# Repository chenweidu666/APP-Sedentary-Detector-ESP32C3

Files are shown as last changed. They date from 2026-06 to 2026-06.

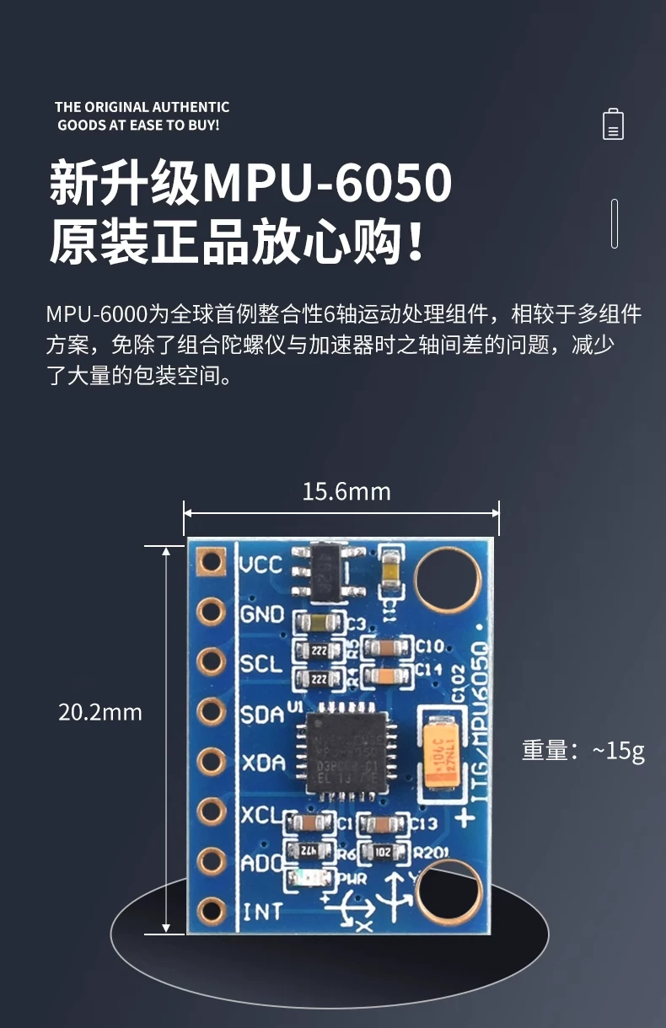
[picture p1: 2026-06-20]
hardware/images/6050.png

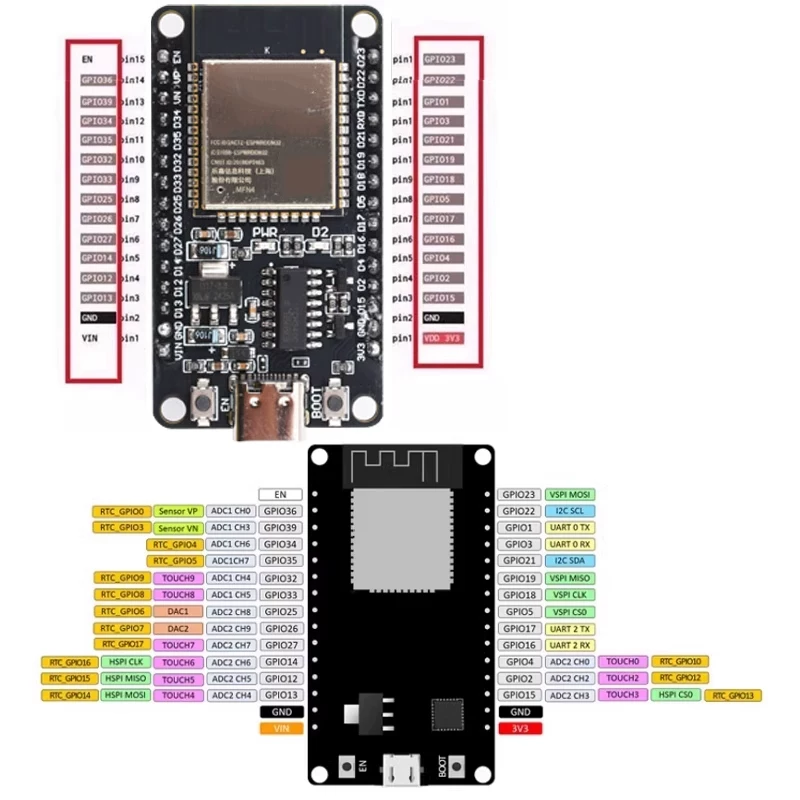
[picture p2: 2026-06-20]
hardware/images/esp32-wroom-32-pinout.jpg

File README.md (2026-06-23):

# Sedentary Detector ESP32 - 久坐检测器

<p align="center">
  
  
  
  
  
</p>

基于 **ESP32-WROOM-32** + **GY-87**（MPU6050）+ **OLED** 的椅子久坐检测器载板方案。本仓库**仅保留硬件**（BOM、接线、KiCad）；固件与联调在独立项目中完成。

**策略**：现成模块 + 定制载板 PCB 插接互连；PM11 锂电包供电（USB 充电，模块自带开关）。

**载板布线节奏**：KiCad 已完成原理图、布局与网络分配；**PCB 尚未布线**。固件与算法仍在 [03](../../03-ESP32-OLED-Button-Demo) / [04](../../04-MCU-GY87-Debug) 中联调，接口与引脚稳定后再走线、DRC、打样，避免返工。

## 当前进度

| 模块 | 状态 |
|---|---|
| 硬件方案 | ✅ MCU + GY-87 + OLED + PM11（无载板按键/开关） |
| 原理图 | ✅ v0.6（J1–J4 网络） |
| 载板 PCB | 🔧 v0.4 已布局 + 网络分配 + J2 对齐；**未布线**（等软件联调稳定后走线打样） |
| GY-87 / IMU 联调 | 🔧 [04-MCU-GY87-Debug](../../04-MCU-GY87-Debug) 调试中 |
| OLED 联调 | 🔧 [03-ESP32-OLED-Button-Demo](../../03-ESP32-OLED-Button-Demo) 调试中 |
| 3D 底座 | ⏳ 待设计 |

## 系统架构

```
         USB 充电
            │
    ┌───────┴────────────────────────────┐
    │  PM11 电源 (自带 ON/OFF)              │
    │       5V / GND                       │
    └───────┬────────────────────────────┘
            │ J3
    ┌───────┴────────────────────────────┐
    │  载板 PCB (100×80)                  │
    │  ┌─────────┐  I2C   ┌──────────┐   │
    │  │ GY-87   │═══════│ ESP32    │   │
    │  │ J2      │       │ DevKitC  │   │
    │  └─────────┘       │ J1       │   │
    │  ┌─────────┐       └──────────┘   │
    │  │ OLED    │═══════ (共享 I2C)     │
    │  │ J4      │                       │
    │  └─────────┘                       │
    └────────────────────────────────────┘
```

检测算法与固件开发见下方**关联软件项目**。

## 文档

| 文档 | 内容 |
|---|---|
| [hardware/HARDWARE.md](hardware/HARDWARE.md) | **硬件权威**：BOM、网络表、模块引脚、电源、PCB 版本 |
| [AGENTS.md](AGENTS.md) | AI / KiCad 自动化工作流 |

### KiCad 载板工程

```bash
kicad hardware/kicad/SedentaryDetector.kicad_pro
```

打样前核对 [hardware/HARDWARE.md §PCB 版本记录](hardware/HARDWARE.md#pcb-版本记录)。

### 关联软件项目（本仓库不含固件源码）

| 项目 | 内容 |
|---|---|
| [03-ESP32-OLED-Button-Demo](../../03-ESP32-OLED-Button-Demo) | SSD1306 OLED + I2C |
| [04-MCU-GY87-Debug](../../04-MCU-GY87-Debug) | GY-87 / MPU6050、久坐检测、BLE |

## 项目结构

```
02-APP-Sedentary-Detector-ESP32/
├── README.md          # 本文件（仓库唯一 README）
├── AGENTS.md
└── hardware/
    ├── HARDWARE.md
    ├── images/
    ├── kicad/
    └── scripts/
```

## 里程碑

| 阶段 | 目标 | 状态 |
|---|---|---|
| M1 模块联调 | 杜邦线验证 GY-87 + OLED（03/04） | 🔧 |
| M2 载板 | 软件稳定后 PCB 布线 → DRC → 打样焊接 | ⏳ |
| M3 整合 | 载板 + 03/04 固件合并产品化 | ⏳ |

## License

MIT

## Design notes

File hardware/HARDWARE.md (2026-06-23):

# 硬件设计文档

> **主控**：ESP32-WROOM-32 开发板（ESP32-DevKitC 风格，2×15 排针载板）。非 ESP32-C3。

## 采购链接

| 模块 | 链接 |
| --- | --- |
| ESP32-WROOM-32 开发板 | https://detail.tmall.com/item.htm?id=805161973303&skuId=5879086331469 |
| 陀螺仪模块 | **GY-87**（10DOF，固件用 MPU6050） | 淘宝/立创搜 GY-87 |
| PM11锂电池包 (3.7V+充电+升压5V/2.4A) | https://item.taobao.com/item.htm?id=1007451636387&skuId=6002389453662 |
| 0.96寸 OLED (I2C) | 128×64 SSD1306, 4Pin (VCC/GND/SCL/SDA) | 淘宝搜 0.96 OLED I2C |

---

## 模块引脚

### ESP32-WROOM-32 开发板 (ESP32-DevKitC 风格)

ESP32-WROOM-32 引脚图

```
尺寸: 51.85 × 23.5 mm
引脚: 左列 15pin + 右列 14pin, 2.54mm 间距, 排针间距 23.5mm
安装孔: 4× φ3mm, 距边 3mm
```

#### 左侧引脚 (从上到下, 15 pin)

| Pin | 丝印 | 功能说明 |
| --- | --- | --- |
| 1 | EN | 使能/复位引脚 (高电平有效) |
| 2 | UP (VP) | GPIO36, ADC1_CH0, 仅输入 |
| 3 | UN (VN) | GPIO39, ADC1_CH3, 仅输入 |
| 4 | D34 | GPIO34, ADC1_CH6, 仅输入 |
| 5 | D35 | GPIO35, ADC1_CH7, 仅输入 |
| 6 | D32 | GPIO32, ADC1_CH4 / TOUCH9  |
| 7 | D33 | GPIO33, ADC1_CH5 / TOUCH8  |
| 8 | D25 | GPIO25, ADC2_CH8 / DAC_1 |
| 9 | D26 | GPIO26, ADC2_CH9 / DAC_2 |
| 10  | D27 | GPIO27, ADC2_CH7 / TOUCH7  |
| 11  | D14 | GPIO14, ADC2_CH6 / TOUCH6  |
| 12  | D12 | GPIO12, ADC2_CH5 / TOUCH5  |
| 13  | D13 | GPIO13, ADC2_CH4 / TOUCH4  |
| 14  | GND | 接地 |
| 15  | VIN | 外部电源输入 (5V) |

#### 右侧引脚 (从上到下, 15 pin)

| Pin | 丝印 | 功能说明 |
| --- | ---- | --- |
| 16  | D23  | GPIO23, VSPI MOSI |
| 17  | D22  | GPIO22, I2C SCL (备用) |
| 18  | TXD  | GPIO1, UART0 TXD |
| 19  | RXD  | GPIO3, UART0 RXD |
| 20  | D21  | GPIO21, I2C SDA (备用) |
| 21  | D19  | GPIO19, VSPI MISO |
| 22  | D18  | GPIO18, VSPI SCK |
| 23  | D5 | GPIO5, VSPI SS / I2C SCL |
| 24  | D17  | GPIO17, UART2 TXD |
| 25  | D16  | GPIO16, UART2 RXD |
| 26  | D4 | GPIO4, I2C SDA |
| 27  | D2 | GPIO2, 板载 LED / MPU INT |
| 28  | D15  | GPIO15, U0 RTS |
| 29  | GND  | 接地 |
| 30  | 3V3  | 3.3V 电源输出 |

> ⚠️ 注意事项:
>
> - GPIO34~39 仅输入，无输出、无内上下拉
> - GPIO6~11 被 SPI Flash 占用，不建议使用
> - GPIO12 (D12) 上电影响 Flash 电压 (MTDI)，上电时保持低
> - GPIO0 下载模式 (板子底部 BOOT 按钮)
> - 板载 LED 在 D2 (GPIO2)

### GY-87 模块（正式选型）

GY-87 10DOF 模块实物（联调）

10DOF 蓝板，丝印 **GY-87**（MPU6050 + HMC5883L + BMP180）。久坐检测**仅使用 MPU6050 加速度计**，磁力计/气压计与固件无关。

```
引脚: 1 × 8pin 单排, 2.54mm
模块**背面**丝印（如上图，从左至右）: VCC_IN · 3.3V · GND · SCL · SDA · FSYNC · INTA · DRDY
载板 J2 排母（J2 Pin1 = VCC_IN, Pin8 = DRDY），与模块背照丝印顺序一致
```

#### J2 排母引脚映射（载板 / 直插）

| J2 Pin | GY-87 丝印 | 网络 | 连接 |
| --- | --- | ---- | ---- |
| 1 | **VCC_IN** | 3V3 | ESP32 Pin30 (3V3) |
| 2 | **3.3V** | — | **不接**（NC） |
| 3 | **GND** | GND | ESP32 GND |
| 4 | **SCL** | I2C_SCL | ESP32 Pin23 (D5) |
| 5 | **SDA** | I2C_SDA | ESP32 Pin26 (D4) |
| 6 | **FSYNC** | — | NC |
| 7 | **INTA** | MPU_INT | ESP32 Pin27 (D2) |
| 8 | **DRDY** | — | NC |

I2C 扫描：

```
0x68  MPU6050（固件使用）
0x77  BMP180（GY-87 自带，忽略）
0x1E  HMC5883L（可选，固件未用）
```

> **PCB 版本**：见文末 [PCB 版本记录](#pcb-版本记录)。

#### 杜邦线联调（ESP32 扩展板）

| GY-87 丝印 | 扩展板 | 线色（参考） |
| --- | --- | --- |
| VCC_IN | **3V3** | 红 |
| GND | **GND** | 橙 |
| SCL | **D5** | 黄 |
| SDA | **D4** | 绿 |
| INTA | **D2** | 蓝（可选） |
| 3.3V / FSYNC / DRDY | 不接 | — |

联调已验证（2026-06-22）：`0x68` + `0x77`，竖放基准角约 97°，`mock=0` 正常。

---

### 传感器安装姿态

**当前台架**：GY-87 **竖直立放**（芯片面垂直于桌面），非最终椅子安装姿态。

| 姿态 | 典型读数 | 说明 |
| ---- | --- | ---- |
| 水平放置（Z 轴朝上） | 基准角 ≈ **0°** | 最终坐垫下安装目标姿态 |
| **竖直立放（当前）** | 基准角 ≈ **±90°**（实测约 **97°**） | 正常；算法看 **delta**，不是绝对角 |

竖放时上电校准后 `baseline` 约在 **90° 附近**，静止时 `delta` 应 **< 0.5°**、`state=VAC`。  
有人/受压时 **倾斜 1° 以上**（`delta > 1.0°`）才判为 `OCCUPIED`。

**最终产品**：模块应 **水平** 固定在坐垫下方，装好后串口发 `c` 重校准（基准角约 0°）。

### OLED 显示屏

1.54 寸 OLED（SSD1306, 128×64），I2C 接口，与 GY-87 共享 I2C 总线。

| OLED Pin | 网络 | 接 ESP32 |
|---|---|---|
| VCC | 3V3 | Pin30 (3V3) |
| GND | GND | Pin14/29 (GND) |
| SCL | I2C_SCL | Pin23 (D5) |
| SDA | I2C_SDA | Pin26 (D4) |

I2C 地址：**0x3C**（与 GY-87 的 0x68 不冲突）。

### 供电模块 (PM11 电源板)

供电模块 PCB 布局

集成 **USB 充电 + 锂电管理 + 多路电源输出** 的独立电源板，通过排针向 ESP32 载板供电。

#### 外形尺寸

| 参数 | 值 |
|---|-----|
| PCB 尺寸 | **56.0 × 40.0 mm** |
| 安装孔间距 | 水平 **48.0 mm** × 垂直 **32.0 mm** |
| 安装孔 | 四角 M3（图中标注孔径约 φ4.7 mm，以实物为准） |
| 板厚 | 1.6 mm（常规） |

#### 板载功能

| 功能 | 说明 |
|---|---|
| USB 输入 | 左侧 USB 口，用于充电与外部供电 |
| ON/OFF 开关 | 左侧滑动开关，物理通断输出 |
| 电量指示 | 左侧四档 LED：**100% / 75% / 50% / 25%** |
| 充电管理 | TP4056 类充电 IC + 外围 RC |
| 电池接口 | 顶部 **4Pin** 电池座，丝印 **+ / −** 极性 |
| 电源输出 | 顶部 **2×6** 排针（2.54 mm） |

#### 2×6 排针（本设计关注）

排针位于板子顶部左侧区域；**底排**为常用电源轨（丝印可见）：

| 排针信号 | 说明 | 载板连接 |
|---|---|---|
| **VBAT** | 电池电压（未稳压） | 一般不接 ESP32 |
| **5V** | 升压/稳压 5V 输出 | → ESP32 **Pin15 (VIN)** |
| **3V3** | 3.3V 输出 | 备用；GY-87 从 ESP32 Pin30 取 3V3 |
| GND | 共地 | → ESP32 **Pin14/29** + 载板 GND 铺铜 |

> 上排 6Pin 功能以实物丝印为准；收到模块后**用万用表核对**再焊线。

#### 本设计电源路径

```
USB ──→ [供电模块] ── ON/OFF ──→ 5V 排针 ──→ 载板 ──→ ESP32 Pin15 (VIN)
              │                              │
              └── 电池 (4Pin +/-)             └── GND ──→ ESP32 GND
              └── 电量 LED (100/75/50/25%)

ESP32 板载 LDO: VIN(5V) → 3V3 Pin30 → GY-87 VCC_IN
```

#### 注意事项

1. 电池 **+/−** 切勿接反
2. 开关 OFF 时 ESP32 完全断电；ON 后 5V 才输出到排针
3. 充电时 USB 插入即可，与 ESP32 是否上电无关
4. D2 (GPIO2) 接 GY-87 **INTA**，与 ESP32 板载 LED 共用

---

## 载板全网络表

| 网络 | J1 (ESP32) | J2 (GY-87) | J3 (电源) | J4 (OLED) |
|---|---|---|---|---|
| 3V3 | Pin30 | Pin1(VCC_IN) | — | Pin1(VCC) |
| 5V | Pin15(VIN) | — | Pin2 | — |
| GND | Pin14,29 | Pin3 | Pin1 | Pin2 |
| I2C_SCL | Pin23(D5) | Pin4(SCL) | — | Pin3 |
| I2C_SDA | Pin26(D4) | Pin5(SDA) | — | Pin4 |
| MPU_INT | Pin27(D2) | Pin7(INTA) | — | — |

载板**无**载板级滑动开关与按键；电源通断由 **PM11 自带 ON/OFF** 控制。

---

## 电源路径

```
供电模块 5V 排针 → 载板走线 → ESP32 Pin15 (VIN)
供电模块 GND     → 载板 GND  → ESP32 Pin14/29
```

## 载板 BOM

| # | 元件 | 规格 | 封装 | 数量 |
| - | ---- | ---- | ---- | :--: |
| 1 | ESP32 排母 (左) | 1×15P 2.54mm | 直插 | 1 |
| 2 | ESP32 排母 (右) | 1×15P 2.54mm | 直插 | 1 |
| 3 | GY-87 排母 J2 | 1×8P 2.54mm | 直插 | 1 |
| 4 | OLED 排母 J4 | 1×4P 2.54mm | 直插 | 1 |
| 5 | JST 电源座 J3 | JST-PH 2.0mm 2P | 直插 | 1 |
| 6 | PCB | 100×80mm 2层 1.6mm | - | 5 |

## 固件与交互

本仓库**不包含固件源码**。联调与算法在 sibling 项目中维护：

| 能力 | 项目 |
|---|---|
| GY-87 / MPU6050、久坐检测、BLE | [04-MCU-GY87-Debug](../../04-MCU-GY87-Debug) |
| SSD1306 OLED、I2C 显示 | [03-ESP32-OLED-Button-Demo](../../03-ESP32-OLED-Button-Demo) |

载板无按键；校准与调试使用上述项目中的串口命令与固件。

**I2C 设备**

| 设备 | 地址 |
|---|---|
| MPU6050 (GY-87) | 0x68 |
| BMP180 (GY-87, 忽略) | 0x77 |
| SSD1306 OLED | 0x3C |

## PCB 版本记录

**当前阶段**：原理图 v0.6、PCB 布局与网络分配已完成，J2 与 GY-87 引脚顺序已对齐。**载板尚未布线**——固件与久坐算法仍在 [03-ESP32-OLED-Button-Demo](../../03-ESP32-OLED-Button-Demo) / [04-MCU-GY87-Debug](../../04-MCU-GY87-Debug) 中联调；软件侧接口稳定后再完成走线、DRC 与打样。

| 版本 | 日期 | 变更 |
|---|---|---|
| 原理图 v0.6 | 2026-06 | 仅 J1 MCU + J2 GY-87 + J3 电源 + J4 OLED；移除载板按键/滑动开关 |
| PCB v0.4 | 2026-06 | 布局 + 网络分配；J2 可直插 GY-87；**走线待软件联调完成后进行** |

## PCB 规格

| 参数 | 值 |
| --- | --- |
| 尺寸 | 100mm × 80mm, 2层 |
| 板厚 | 1.6mm |
| 铜厚 | 1oz |
| 安装孔 | 4× M3 (φ3.2mm), 距边 3mm |
| 线宽 (信号) | 0.254mm |
| 线宽 (电源) | 0.5mm |
| GND | B.Cu 铺铜 |

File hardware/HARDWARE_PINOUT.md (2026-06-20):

# ESP32-WROOM-32 引脚定义 (2×15, 30 Pin)

## 左列引脚 (Pin 1-15, 从上到下)

| Pin | 引脚 | 功能说明 |
|-----|---|---|
| 1 | 3V3 | 3.3V 电源输出 |
| 2 | EN | 使能/复位 (高电平有效) |
| 3 | GPIO36 | VP, ADC1_CH0, 仅输入 |
| 4 | GPIO39 | VN, ADC1_CH3, 仅输入 |
| 5 | GPIO34 | ADC1_CH6, 仅输入 |
| 6 | GPIO35 | ADC1_CH7, 仅输入 |
| 7 | GPIO32 | ADC1_CH4 / TOUCH9 |
| 8 | GPIO33 | ADC1_CH5 / TOUCH8 |
| 9 | GPIO25 | ADC2_CH8 / DAC_1 |
| 10 | GPIO26 | ADC2_CH9 / DAC_2 |
| 11 | GPIO27 | ADC2_CH7 / TOUCH7 |
| 12 | GPIO14 | ADC2_CH6 / TOUCH6 / MTMS |
| 13 | GPIO12 | ADC2_CH5 / TOUCH5 / MTDI |
| 14 | GND | 接地 |
| 15 | VIN | 外部电源输入 (5V) |

## 右列引脚 (Pin 16-30, 从上到下)

| Pin | 引脚 | 功能说明 |
|-----|---|---|
| 16 | GPIO23 | VSPI MOSI |
| 17 | GPIO22 | I2C SCL |
| 18 | GPIO21 | I2C SDA |
| 19 | GND | 接地 |
| 20 | GPIO19 | VSPI MISO |
| 21 | GPIO18 | VSPI SCK |
| 22 | GPIO5 | VSPI SS / TOUCH5 |
| 23 | GPIO17 | UART2 TXD |
| 24 | GPIO16 | UART2 RXD |
| 25 | GPIO4 | TOUCH0 / ADC2_CH0 |
| 26 | GPIO2 | TOUCH2 / 板载LED |
| 27 | GPIO15 | U0 RTS / TOUCH3 |
| 28 | GND | 接地 |
| 29 | 3V3 | 3.3V 电源输出 |
| 30 | NC | 未使用 |

## 本设计使用的引脚

| ESP32 引脚 | Pin# | 连接 |
|---|---|---|
| GPIO4 (SDA) | 25 | → MPU6050 SDA |
| GPIO5 (SCL) | 22 | → MPU6050 SCL |
| GPIO2 (INT) | 26 | → MPU6050 INT |
| VIN | 15 | ← PM11 5V (经开关) |
| 3V3 | 1 | → MPU6050 VCC |
| GND | 14/19/28 | → 共地 |
| GPIO14 | 12 | → 扩展 Pin1（预留） |
| GPIO25 | 9 | → 扩展 Pin2（预留） |
| GPIO26 | 10 | → 扩展 Pin3（预留） |

## 固件引脚配置

```cpp
// Arduino: I2C 非默认引脚
Wire.begin(4, 5);  // SDA=GPIO4, SCL=GPIO5
// INT 接 GPIO2（与板载 LED 共用）
```

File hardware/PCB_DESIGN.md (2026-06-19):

# 载板 PCB 设计文档

## 采购链接

| 模块 | 链接 |
|---|---|
| ESP32-C3 Mini 开发板 | https://detail.tmall.com/item.htm?id=805161973303&skuId=5879086331469 |
| 陀螺仪模块 (MPU6050/GY-521) | https://detail.tmall.com/item.htm?id=729656168752&skuId=5367169145529 |
| TP4056 Type-C 充放电模块 | 已取消 (PM11 电池模块自带充电+升压) |
| SS-12D00 滑动开关 | 待补充 |
| JST-PH 2.0 座子 | 待补充 |
| PM11锂电池包 (3.7V+充电+升压5V/2.4A) | https://item.taobao.com/item.htm?id=1007451636387&skuId=6002389453662 |

## 概述

载板 (Carrier Board) 用于插接两个现成开发板模块（ESP32-C3 Mini、GY-521），通过 PCB 走线完成模块间互连，替代杜邦线。板上集成滑动开关。电池使用 PM11锂电池包（自带充电+升压 5V/2.4A），无需额外充放电模块。

## 规格参数

| 参数 | 值 |
|---|-----|
| PCB 尺寸 | 50mm × 35mm (2 层) |
| 工作电压 | 5V (PM11 电池模块升压输出) |
| 模块插接 | 排母座 2.54mm 间距 |
| 电池接口 | PM11 自带 JST 接口 (直连载板) |
| 开关 | SS-12D00 滑动开关 |
| 扩展 | 预留 4 个 GPIO 排针 |

---

## 模块尺寸与引脚

### ESP32-C3 Mini 开发板 (合宙)

```
尺寸: ~25.4 × 18.0 mm
引脚: 2 × 9pin 排针, 2.54mm 间距

            USB-C (上方)
     ┌─────────────────────┐
     │ O                 O │
 GND │ ●  [ESP32-C3 Mini] ● │ GND
  5V │ ●                  ● │ 3V3
 IO0 │ ●                  ● │ IO10
 IO1 │ ●                  ● │ IO9
 IO2 │ ●  ← INT (唤醒)    ● │ IO8
 IO3 │ ●                  ● │ IO7
 IO4 │ ●  ← SDA           ● │ IO6
 IO5 │ ●  ← SCL           ● │ IO5
  RX │ ●                  ● │ TX
     │ O                 O │
     └─────────────────────┘

注: 引脚排列以实际开发板丝印为准，购买后核对。
本设计使用:
  - GPIO4 → SDA (I2C 数据)
  - GPIO5 → SCL (I2C 时钟)
  - GPIO2 → MPU6050 INT (运动中断唤醒)
  - 5V/VIN → 电源输入 (3.7V 电池经开关接入)
  - GND → 共地
```

### GY-521 模块 (MPU6050)

```
尺寸: ~21 × 16 mm
引脚: 1 × 8pin 单排, 2.54mm 间距

     ┌─────────────────┐
     │                 │
     │   [MPU6050]     │
     │    GY-521       │
     │                 │
     └─┬─┬─┬─┬─┬─┬─┬─┬┘
       │ │ │ │ │ │ │ │
      VCC GND SCL SDA XDA XCL AD0 INT

本设计使用 (5 根):
  - VCC → 3V3
  - GND → GND
  - SCL → ESP32 GPIO5
  - SDA → ESP32 GPIO4
  - INT → ESP32 GPIO2
未使用: XDA, XCL, AD0 (AD0 默认接 GND, I2C 地址 0x68)
```

### PM11锂电池包 (自带充电+升压)

```
尺寸: ~40 × 20 × 12mm (含外壳)
接口: JST-PH 2.0 (输出 5V/2.4A)

功能:
  - 3.7V LiPo 电池内置
  - TP4056 充电电路 (Micro-USB/Type-C 充电)
  - 升压模块5V/2.4A输出
  - 低电量保护

本设计使用:
  - 5V 输出 → 滑动开关 → ESP32 VIN
  - GND → ESP32 GND
  - 充电口外露, 无需载板走线
```

---

## 载板原理图

```
                         载板 PCB 连接关系
┌──────────────────────────────────────────────────────────┐
│                                                          │
│  PM11 电池模块 (5V 输出)                                  │
│   5V ──────── SS-12D00 开关 ─────── ESP32 VIN (5V)       │
│   GND ─────── GND (共地总线)                              │
│                                                          │
│  ESP32 3V3 ──────── GY-521 VCC                           │
│  ESP32 GND ──────── GY-521 GND                           │
│  ESP32 GPIO4 ────── GY-521 SDA                           │
│  ESP32 GPIO5 ────── GY-521 SCL                           │
│  ESP32 GPIO2 ────── GY-521 INT                           │
│                                                          │
│  扩展排针: GPIO3, GPIO6, GPIO7, GPIO8 (预留)              │
│                                                          │
└──────────────────────────────────────────────────────────┘
```

---

## PCB 布局建议

```
          50mm
┌──────────────────────────────────┐
│                                  │  ↑
│  ┌──────────────┐  ┌─────────┐  │
│  │  ESP32-C3    │  │ GY-521  │  │
│  │  Mini        │  │ MPU6050 │  │
│  │  (排母 2×9)   │  │(排母1×8)│  │  35mm
│  │              │  │         │  │
│  └──────────────┘  └─────────┘  │
│                                  │
│  [开关]  [PM11电池JST]           │
│  SS-12D00  JST-PH 2P             │
│  ○ ○ ○ ○                         │
│  扩展GPIO                        │
│          ↑ USB-C 充电口朝外       │
└──────────────────────────────────┘

安装孔: 四角 M3 (φ3.2mm), 距边 3mm
```

### 布局要点

1. **MPU6050 居中**: 传感器尽量靠近 PCB 中心，减少安装偏差
2. **开关在边缘**: 滑动开关伸出 PCB 侧面，方便操作
3. **PM11 JST 座**: 靠近 PCB 边缘，电池平放底座内
4. **扩展排针**: 留在 PCB 边缘空闲位置，以后加传感器/执行器

---

## 布线规则

| 参数 | 值 |
|---|-----|
| 最小线宽 | 10mil (0.254mm) |
| 电源线 (VIN/3V3) | 20mil (0.5mm) |
| GND | 大面积铺铜 |
| 最小间距 | 8mil |
| 过孔 | 0.3mm 孔径 / 0.6mm 焊盘 |
| 板厚 | 1.6mm |
| 铜厚 | 1oz |

---

## 载板 BOM

| # | 元件 | 型号/规格 | 封装 | 数量 | 备注 |
|---|---|---|---|:----:|---|
| 1 | 排母座 (ESP32) | 1×9P 2.54mm | 直插 | 2 | 双排插接 ESP32-C3 Mini |
| 2 | 排母座 (MPU6050) | 1×8P 2.54mm | 直插 | 1 | 插接 GY-521 |
| 3 | 滑动开关 | SS-12D00 | 直插 3P | 1 | 电源通断 |
| 4 | JST-PH 座子 | PH 2.0mm 2P | 卧式直插 | 1 | PM11 电池接口 |
| 5 | 排针 (扩展) | 1×4P 2.54mm | 直插 | 1 | 预留 GPIO 扩展 |
| 6 | PCB 打样 | 50×35mm 2层 | - | 5 | 嘉立创 5 片起打 |

**载板物料合计: ≈ ¥5**

---

## 嘉立创 EDA 操作步骤

### 1. 新建项目

1. 打开 https://lceda.cn → 登录 → 新建项目 → "Sedentary-Detector-CarrierBoard"
2. 新建原理图

### 2. 放置元件

在原理图编辑器中搜索并放置:

| 搜索关键词 | 元件 | 数量 |
|---|---|:----:|
| `Header Female 1x9` | 2.54mm 排母 1×9P | 2 |
| `Header Female 1x8` | 2.54mm 排母 1×8P | 1 |
| `SS-12D00` 或 `SS12D00` | 滑动开关 | 1 |
| `JST PH 2P` 或 `B2B-PH` | JST-PH 2.0 座子 | 1 |
| `Header Male 1x4` | 2.54mm 排针 1×4P | 1 |

### 3. 原理图连线

按上面"载板原理图"一节的连接关系画网络:

```
网络名       连接
─────       ────
VIN         PM11.5V → SW.COM → ESP32.VIN
3V3         ESP32.3V3 → GY521.VCC
GND         ESP32.GND → GY521.GND → PM11.GND
SDA         ESP32.GPIO4 → GY521.SDA
SCL         ESP32.GPIO5 → GY521.SCL
INT         ESP32.GPIO2 → GY521.INT
5V          JST.PIN1 (PM11 5V 输出) → 开关
GND_JST     JST.PIN2 (PM11 GND) → GND
```

### 4. 转 PCB 并布局

1. 菜单 → `设计` → `原理图转PCB`
2. 设置板框: 50 × 35mm
3. 按"PCB 布局建议"摆放元件
4. 四角放 M3 安装孔 (焊盘 → 过孔 → φ3.2mm)
5. 手动布线 / 自动布线
6. 底层铺铜 GND

### 5. 检查与下单

1. `设计` → `DRC 检查` → 修正所有错误
2. `制造` → `PCB 订单` → 预览 Gerber
3. 选: 2 层, 1.6mm, 绿油白丝印, 5 片
4. 嘉立创新用户首单免费

---

## 3D 底座配合

载板 PCB 四角 M3 安装孔与 3D 打印底座对应:

```
底座截面 (侧视):

    ┌─ 载板 PCB ──────────┐
    │  (M3 螺丝固定)       │
 ───┴──────────────────────┴───  ← 底座上表面
 │         LiPo 电池            │  ← 电池仓 (底座内)
 │         (扁平软包)            │
 └──────────────────────────────┘  ← 底座底面 (贴椅子)
         ↑ 双面胶/扎带固定到椅子
```

底座内部预留:
- 电池仓: 50 × 30 × 8mm (适配 1000mAh 扁平 LiPo)
- PCB 固定柱: 4 个 M3 铜柱, 高度 10mm (电池上方)
- Type-C 开口: 侧面留缺口
- 开关开口: 侧面留缺口

---

## 载板 PCB 接线表 (立创 EDA 直接可用)

> ⚠️ **重要**: 以下引脚定义基于常见 ESP32-C3 Mini 排布。收到板后**务必用万用表核对丝印**，如有差异在此更新。

### ESP32-C3 Mini 排母 (2×9P, 双排)

```
排母 A (左侧, 1×9P):
Pin 1  → GND
Pin 2  → 3V3  (板载 LDO 输出 3.3V, 供 MPU6050)
Pin 3  → GPIO0 (BOOT, 烧录用)
Pin 4  → GPIO1 (预留扩展)
Pin 5  → GPIO2 (MPU6050 INT 中断唤醒)
Pin 6  → GPIO3 (预留扩展)
Pin 7  → GPIO4 (MPU6050 SDA, I2C 数据)
Pin 8  → GPIO5 (MPU6050 SCL, I2C 时钟)
Pin 9  → GND

排母 B (右侧, 1×9P):
Pin 1  → GND
Pin 2  → VIN  (5V 输入, 经开关接 PM11 5V OUT)
Pin 3  → GPIO6  (预留扩展)
Pin 4  → GPIO7  (预留扩展)
Pin 5  → GPIO8  (预留扩展)
Pin 6  → GPIO9  (预留扩展)
Pin 7  → GPIO10 (预留扩展)
Pin 8  → RX     (预留扩展)
Pin 9  → TX     (预留扩展)
```

### GY-521 MPU6050 排母 (1×8P)

```
Pin 1  → VCC  (接 ESP32 3V3)
Pin 2  → GND  (接 ESP32 GND)
Pin 3  → SCL  (接 ESP32 GPIO5)
Pin 4  → SDA  (接 ESP32 GPIO4)
Pin 5  → XDA  → 不接 (I2C 辅助, 用不到)
Pin 6  → XCL  → 不接
Pin 7  → AD0  → 不接 (默认 GND, I2C 地址 0x68)
Pin 8  → INT  (接 ESP32 GPIO2)
```

### PM11 电池模块 JST-PH 2P

```
Pin 1 (红) → 5V OUT (经 SS-12D00 开关 → ESP32 VIN)
Pin 2 (黑) → GND (直连 ESP32 GND)
```

### SS-12D00 滑动开关 (3P)

```
Pin 1 → PM11 5V OUT (常开端)
Pin 2 → 公共端 → ESP32 VIN
Pin 3 → 悬空 (或接 Pin1 作常闭)
```

### 扩展排针 (1×4P)

```
Pin 1 → GPIO1 (可复用)
Pin 2 → GPIO3 (可复用)
Pin 3 → GPIO6 (可复用)
Pin 4 → GND
```

---

## 载板 PCB 网络表 (立创 EDA 原理图画线用)

| 网络名 | 起点 | 终点 | 线宽建议 |
|---|---|---|---|
| 5V_PM11 | JST Pin1 | 开关 Pin1 | 20mil |
| VIN_SW | 开关 Pin2 | ESP32 VIN (排母B Pin2) | 20mil |
| GND | JST Pin2 → ESP32 GND → GY521 GND | 大面积铺铜 | 铺铜 |
| 3V3 | ESP32 3V3 (排母A Pin2) → GY521 VCC | 15mil |
| I2C_SDA | ESP32 GPIO4 (排母A Pin7) → GY521 SDA | 10mil |
| I2C_SCL | ESP32 GPIO5 (排母A Pin8) → GY521 SCL | 10mil |
| MPU_INT | ESP32 GPIO2 (排母A Pin5) → GY521 INT | 10mil |
| EXT1 | ESP32 GPIO1 (排母A Pin4) → 扩展 Pin1 | 10mil |
| EXT2 | ESP32 GPIO3 (排母A Pin6) → 扩展 Pin2 | 10mil |
| EXT3 | ESP32 GPIO6 (排母B Pin3) → 扩展 Pin3 | 10mil |
| EXT_GND | ESP32 GND → 扩展 Pin4 | 铺铜 |

---

## 立创 EDA 原理图绘制步骤 (精简版)

### 1. 放置元件

| 搜索关键词 | 元件 | 数量 |
|---|---|:----:|
| `Header Female 1x9` | 2.54mm 排母 1×9P | 2 |
| `Header Female 1x8` | 2.54mm 排母 1×8P | 1 |
| `SS-12D00` | 滑动开关 | 1 |
| `JST PH 2P` 或 `B2B-PH-SM` | JST-PH 2.0 座子 | 1 |
| `Header Male 1x4` | 2.54mm 排针 1×4P | 1 |

### 2. 连线 (按网络表)

对照上面"网络表"逐条画线。核心 3 条线:
- **5V_PM11 → VIN_SW**: PM11 5V → 开关 → ESP32 VIN (电源线, 20mil)
- **3V3 → GY521 VCC**: ESP32 3V3 → MPU6050 VCC (15mil)
- **I2C**: ESP32 GPIO4/5 → GY521 SDA/SCL (10mil)

### 3. 转 PCB

1. `设计` → `原理图转PCB`
2. 板框: 50 × 35mm
3. 按布局建议摆放元件
4. 四角 M3 安装孔 (φ3.2mm 过孔)
5. 自动布线 → 手动检查电源线 (20mil)
6. 底层铺铜 GND
7. DRC 检查 → 无错误 → 导出 Gerber → 嘉立创下单

### 4. 下单参数

| 参数 | 值 |
|---|-----|
| 层数 | 2 层 |
| 板厚 | 1.6mm |
| 板子颜色 | 绿油白丝印 |
| 数量 | 5 片 |
| 工艺 | 喷锡 |

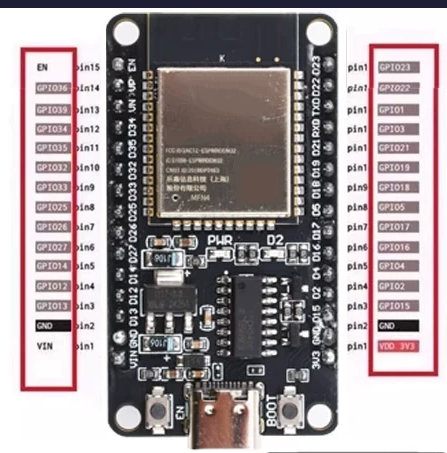
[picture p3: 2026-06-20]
hardware/images/image.png

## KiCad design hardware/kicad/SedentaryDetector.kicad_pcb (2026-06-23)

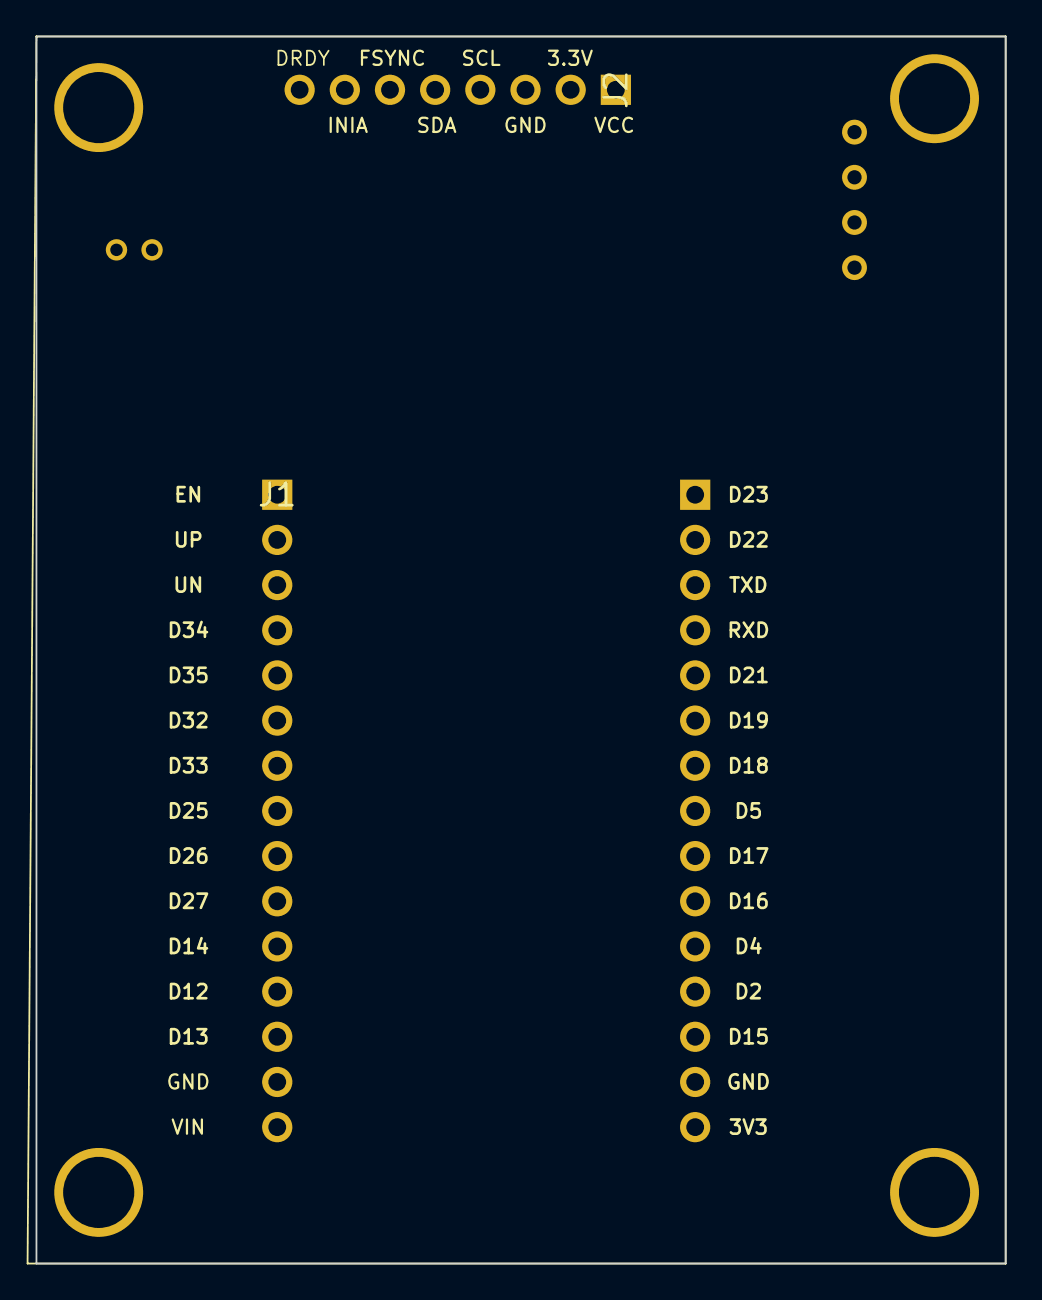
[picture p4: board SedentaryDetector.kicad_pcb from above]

Board: 2 copper layers, 54.5 x 69.0 mm, 8 parts (0 on the bottom side), 6 nets, no tracks yet.

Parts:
J1: ESP32_2x15
J2: GY-87
J3: POWER_2P
J4: OLED_0.96
MH1, MH2, MH3, MH4: (no value)

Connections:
3V3: J1.30 (3V3), J2.1 (VCC_IN), J4.1
5V: J1.15 (VIN), J3.2
GND: J1.14 (GND), J1.29 (GND), J2.3 (GND), J3.1, J4.2
I2C_SCL: J1.23 (D5), J2.4 (SCL), J4.3
I2C_SDA: J1.26 (D4), J2.5 (SDA), J4.4
MPU_INT: J1.27 (D2), J2.7 (INTA)

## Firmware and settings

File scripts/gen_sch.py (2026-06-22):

import uuid

def gen_uuid():
    return str(uuid.uuid4())

uuids = {k: gen_uuid() for k in [
    "file", "esp_sym", "mpu_sym",
    "gnd1", "gnd2", "gnd3", "gnd4",
    "vcc3v3",
]}
for i in range(1, 19):
    uuids[f"esp_pin{i}"] = gen_uuid()
for i in range(1, 9):
    uuids[f"mpu_pin{i}"] = gen_uuid()
for i in range(1, 11):
    uuids[f"wire{i}"] = gen_uuid()
for i in range(1, 5):
    uuids[f"junc{i}"] = gen_uuid()
for name in ["label_gnd", "label_3v3", "label_5v", "label_sda", "label_scl", "label_int"]:
    uuids[name] = gen_uuid()
for i in range(1, 14):
    uuids[f"nc{i}"] = gen_uuid()
for name in ["esp_ref", "mpu_ref", "pwr_gnd1", "pwr_gnd2", "pwr_gnd3", "pwr_gnd4", "pwr_3v3"]:
    uuids[name] = gen_uuid()

# ============================================================
# lib_symbols
# ============================================================
esp_pins = []
for i in range(1, 10):
    y = 10.16 - (i-1) * 2.54
    esp_pins.append(f"""				(pin passive line (at -2.54 {y} 0) (length 2.54)
          (name "{i}" (effects (font (size 1.27 1.27))))
          (number "{i}" (effects (font (size 1.27 1.27))))
        )""")
for i in range(10, 19):
    y = 10.16 - (i-10) * 2.54
    esp_pins.append(f"""				(pin passive line (at 2.54 {y} 0) (length 2.54)
          (name "{i}" (effects (font (size 1.27 1.27))))
          (number "{i}" (effects (font (size 1.27 1.27))))
        )""")

esp_symbol = f"""(symbol "CarrierBoard:ESP32_C3_Mini_2x9" (pin_numbers hide) (pin_names (offset 1.016)) (in_bom yes) (on_board yes)
			(property "Reference" "ESP" (at 0 -10.16 0)
        (effects (font (size 1.27 1.27)) (justify top))
      )
			(property "Value" "ESP32-C3_Mini_2x9" (at 0 -12.7 0)
        (effects (font (size 1.27 1.27)) hide)
      )
			(property "Footprint" "CarrierBoard:ESP32_C3_Mini_2x9" (at 0 13.97 0)
        (effects (font (size 1.27 1.27)) hide)
      )
			(property "Datasheet" "" (at 0 0 0)
        (effects (font (size 1.27 1.27)) hide)
      )
			(symbol "ESP32_C3_Mini_2x9_0_1"
        (rectangle (start -5.08 -12.7) (end 5.08 12.7)
          (stroke (width 0.254) (type default))
          (fill (type background))
        )
      )
			(symbol "ESP32_C3_Mini_2x9_1_1"
{chr(10).join(esp_pins)}
      )
    )"""

mpu_pins = []
mpu_pin_names = {1: "VCC", 2: "GND", 3: "SCL", 4: "SDA", 5: "XDA", 6: "XCL", 7: "AD0", 8: "INT"}
for i in range(1, 9):
    y = 8.89 - (i-1) * 2.54
    mpu_pins.append(f"""				(pin passive line (at 0 {y} 0) (length 2.54)
          (name "{mpu_pin_names[i]}" (effects (font (size 1.27 1.27))))
          (number "{i}" (effects (font (size 1.27 1.27))))
        )""")

mpu_symbol = f"""(symbol "CarrierBoard:GY521_MPU6050_1x8" (pin_numbers hide) (pin_names (offset 1.016)) (in_bom yes) (on_board yes)
			(property "Reference" "MPU" (at 0 -11.43 0)
        (effects (font (size 1.27 1.27)) (justify top))
      )
			(property "Value" "GY-521_MPU6050_1x8" (at 0 -13.97 0)
        (effects (font (size 1.27 1.27)) hide)
      )
			(property "Footprint" "CarrierBoard:GY521_MPU6050_1x8" (at 0 12.7 0)
        (effects (font (size 1.27 1.27)) hide)
      )
			(property "Datasheet" "" (at 0 0 0)
        (effects (font (size 1.27 1.27)) hide)
      )
			(symbol "GY521_MPU6050_1x8_0_1"
        (rectangle (start -5.08 -11.43) (end 5.08 11.43)
          (stroke (width 0.254) (type default))
          (fill (type background))
        )
      )
			(symbol "GY521_MPU6050_1x8_1_1"
{chr(10).join(mpu_pins)}
      )
    )"""

lib_symbols = f"""  (lib_symbols
{esp_symbol}
{mpu_symbol}
		(symbol "power:GND" (power) (pin_names (offset 0)) (in_bom yes) (on_board yes)
			(property "Reference" "#PWR" (at 0 -6.35 0)
        (effects (font (size 1.27 1.27)) hide)
      )
			(property "Value" "GND" (at 0 -3.81 0)
        (effects (font (size 1.27 1.27)))
      )
			(property "Footprint" "" (at 0 0 0)
        (effects (font (size 1.27 1.27)) hide)
      )
			(property "Datasheet" "" (at 0 0 0)
        (effects (font (size 1.27 1.27)) hide)
      )
			(symbol "GND_0_1"
        (polyline
          (pts (xy 0 0) (xy 0 -1.27) (xy 1.27 -1.27) (xy 0 -2.54) (xy -1.27 -1.27) (xy 0 -1.27))
          (stroke (width 0) (type default))
          (fill (type none))
        )
      )
			(symbol "GND_1_1"
				(pin power_in line (at 0 0 270) (length 0) hide
          (name "GND" (effects (font (size 1.27 1.27))))
          (number "1" (effects (font (size 1.27 1.27))))
        )
      )
    )
		(symbol "power:VCC" (power) (pin_names (offset 0)) (in_bom yes) (on_board yes)
			(property "Reference" "#PWR" (at 0 -3.81 0)
        (effects (font (size 1.27 1.27)) hide)
      )
			(property "Value" "+3V3" (at 0 3.81 0)
        (effects (font (size 1.27 1.27)))
      )
			(property "Footprint" "" (at 0 0 0)
        (effects (font (size 1.27 1.27)) hide)
      )
			(property "Datasheet" "" (at 0 0 0)
        (effects (font (size 1.27 1.27)) hide)
      )
			(symbol "+3V3_0_1"
        (polyline
          (pts (xy -1.27 1.27) (xy 0 2.54) (xy 1.27 1.27))
          (stroke (width 0) (type default))
          (fill (type none))
        )
        (polyline
          (pts (xy 0 0) (xy 0 2.54))
          (stroke (width 0) (type default))
          (fill (type none))
        )
      )
			(symbol "+3V3_1_1"
				(pin power_in line (at 0 0 90) (length 0) hide
          (name "+3V3" (effects (font (size 1.27 1.27))))
          (number "1" (effects (font (size 1.27 1.27))))
        )
      )
    )
  )"""

# ============================================================
# Pin coordinates
# ============================================================
esp_at_x, esp_at_y = 50, 80
mpu_at_x, mpu_at_y = 170, 80

def esp_pin_abs(pin_num):
    if pin_num <= 9:
        px = esp_at_x - 2.54
        py = esp_at_y + (10.16 - (pin_num-1) * 2.54)
    else:
        px = esp_at_x + 2.54
        py = esp_at_y + (10.16 - (pin_num-10) * 2.54)
    return (px, py)

def mpu_pin_abs(pin_num):
    px = mpu_at_x
    py = mpu_at_y + (8.89 - (pin_num-1) * 2.54)
    return (px, py)

# ============================================================
# Begin schematic
# ============================================================
content = f"""(kicad_sch (version 20250114) (generator eeschema)

  (uuid {uuids["file"]})

  (paper "A3")
  (title_block
    (title "Sedentary Detector - Carrier Board")
    (date "2026-06-20")
    (rev "0.2")
    (company "Personal Project")
  )
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

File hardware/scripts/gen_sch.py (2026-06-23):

"""从 HARDWARE.md 网络表生成载板原理图骨架（ESP32-WROOM-32 2×15 + GY-87 1×8）。"""

import uuid
from pathlib import Path

ROOT = Path(__file__).resolve().parents[2]
# 默认写入 .gen 文件，避免覆盖 KiCad GUI 中手工维护的原理图
DST = ROOT / "hardware/kicad/SedentaryDetector.gen.kicad_sch"

ESP_NUM_PINS = 30

# DevKitC 排针编号 → 功能名（见 hardware/HARDWARE.md）
ESP_PIN_NAMES = {
    1: "3V3",
    2: "EN",
    3: "GPIO36",
    4: "GPIO39",
    5: "GPIO34",
    6: "GPIO35",
    7: "GPIO32",
    8: "GPIO33",
    9: "GPIO25",
    10: "GPIO26",
    11: "GPIO27",
    12: "GPIO14",
    13: "GPIO12",
    14: "GND",
    15: "VIN",
    16: "GPIO23",
    17: "GPIO22",
    18: "GPIO21",
    19: "GND",
    20: "GPIO19",
    21: "GPIO18",
    22: "GPIO5/SCL",
    23: "GPIO17",
    24: "GPIO16",
    25: "GPIO4/SDA",
    26: "GPIO2/INT",
    27: "GPIO15",
    28: "GND",
    29: "3V3",
    30: "30",
}

# 载板已用网络对应的 ESP 排针编号
PIN_3V3 = 1
PIN_GND_LEFT = 14
PIN_VIN = 15
PIN_GND_MID = 19
PIN_SCL = 22
PIN_SDA = 25
PIN_INT = 26
PIN_GND_RIGHT = 28

USED_ESP_PINS = {
    PIN_3V3,
    PIN_GND_LEFT,
    PIN_VIN,
    PIN_GND_MID,
    PIN_SCL,
    PIN_SDA,
    PIN_INT,
    PIN_GND_RIGHT,
}


def gen_uuid():
    return str(uuid.uuid4())


uuids = {k: gen_uuid() for k in [
    "file", "esp_sym", "mpu_sym",
    "pwr_gnd1", "pwr_gnd2", "pwr_3v3",
    "pwr_gnd1_pin", "pwr_gnd2_pin", "pwr_3v3_pin",
]}
for i in range(1, ESP_NUM_PINS + 1):
    uuids[f"esp_pin{i}"] = gen_uuid()
for i in range(1, 9):
    uuids[f"mpu_pin{i}"] = gen_uuid()
for i in range(1, 12):
    uuids[f"wire{i}"] = gen_uuid()
for i in range(1, 5):
    uuids[f"junc{i}"] = gen_uuid()
for name in ["label_gnd", "label_3v3", "label_5v", "label_sda", "label_scl", "label_int"]:
    uuids[name] = gen_uuid()
nc_idx = 0
for pin in range(1, ESP_NUM_PINS + 1):
    if pin not in USED_ESP_PINS:
        nc_idx += 1
        uuids[f"nc{nc_idx}"] = gen_uuid()
for pin in (1, 3, 7):
    uuids[f"nc_mpu{pin}"] = gen_uuid()


def conn_02x15_pin_lines(side: str, start_num: int, count: int) -> list[str]:
    lines = []
    x = -7.62 if side == "left" else 7.62
    for i in range(count):
        num = start_num + i
        y = 20.32 - i * 2.54
        name = ESP_PIN_NAMES.get(num, str(num))
        lines.append(
            f"""				(pin passive line (at {x} {y} 0) (length 2.54)
          (name "{name}" (effects (font (size 1.27 1.27))))
          (number "{num}" (effects (font (size 1.27 1.27))))
        )"""
        )
    return lines


esp_symbol_pins = conn_02x15_pin_lines("left", 1, 15) + conn_02x15_pin_lines("right", 16, 15)

esp_symbol = f"""(symbol "Conn_02x15" (pin_names (offset 1.016)) (in_bom yes) (on_board yes)
			(property "Reference" "J1" (at 0 20.32 0)
        (effects (font (size 1.27 1.27)) (justify left))
      )
			(property "Value" "ESP32_2x15" (at 0 22.86 0)
        (effects (font (size 1.27 1.27)) (justify left))
      )
			(property "Footprint" "" (at 0 -20.32 0)
        (effects (font (size 1.27 1.27)) hide)
      )
			(property "Datasheet" "" (at 0 0 0)
        (effects (font (size 1.27 1.27)) hide)
      )
			(symbol "Conn_02x15_0_1"
        (rectangle (start -7.62 20.32) (end 7.62 -20.32)
          (stroke (width 0.254) (type default))
          (fill (type background))
        )
      )
			(symbol "Conn_02x15_1_1"
{chr(10).join(esp_symbol_pins)}
      )
    )"""

mpu_pins = []
mpu_pin_names = {
    1: "DRDY",
    2: "INTA",
    3: "FSYNC",
    4: "SDA",
    5: "SCL",
    6: "GND",
    7: "3.3V",
    8: "VCC_IN",
}
for i in range(1, 9):
    y = 8.89 - (i - 1) * 2.54
    mpu_pins.append(
        f"""				(pin passive line (at 0 {y} 0) (length 2.54)
          (name "{mpu_pin_names[i]}" (effects (font (size 1.27 1.27))))
          (number "{i}" (effects (font (size 1.27 1.27))))
        )"""
    )

mpu_symbol = f"""(symbol "CarrierBoard:GY87_1x8" (pin_numbers hide) (pin_names (offset 1.016)) (in_bom yes) (on_board yes)
			(property "Reference" "J2" (at 0 -11.43 0)
        (effects (font (size 1.27 1.27)) (justify top))
      )
			(property "Value" "GY-87_1x8" (at 0 -13.97 0)
        (effects (font (size 1.27 1.27)) hide)
      )
			(property "Footprint" "Connector_PinSocket_2.54mm:PinSocket_1x08_P2.54mm_Vertical" (at 0 12.7 0)
        (effects (font (size 1.27 1.27)) hide)
      )
			(property "Datasheet" "" (at 0 0 0)
        (effects (font (size 1.27 1.27)) hide)
      )
			(symbol "GY87_1x8_0_1"
        (rectangle (start -5.08 -11.43) (end 5.08 11.43)
          (stroke (width 0.254) (type default))
          (fill (type background))
        )
      )
			(symbol "GY87_1x8_1_1"
{chr(10).join(mpu_pins)}
      )
    )"""

lib_symbols = f"""  (lib_symbols
{esp_symbol}
{mpu_symbol}
		(symbol "power:GND" (power) (pin_names (offset 0)) (in_bom yes) (on_board yes)
			(property "Reference" "#PWR" (at 0 -6.35 0)
        (effects (font (size 1.27 1.27)) hide)
      )
			(property "Value" "GND" (at 0 -3.81 0)
        (effects (font (size 1.27 1.27)))
      )
			(property "Footprint" "" (at 0 0 0)
        (effects (font (size 1.27 1.27)) hide)
      )
			(property "Datasheet" "" (at 0 0 0)
        (effects (font (size 1.27 1.27)) hide)
      )
			(symbol "GND_0_1"
        (polyline
          (pts (xy 0 0) (xy 0 -1.27) (xy 1.27 -1.27) (xy 0 -2.54) (xy -1.27 -1.27) (xy 0 -1.27))
          (stroke (width 0) (type default))
          (fill (type none))
        )
      )
			(symbol "GND_1_1"
				(pin power_in line (at 0 0 270) (length 0) hide
          (name "GND" (effects (font (size 1.27 1.27))))
          (number "1" (effects (font (size 1.27 1.27))))
        )
      )
    )
		(symbol "power:VCC" (power) (pin_names (offset 0)) (in_bom yes) (on_board yes)
			(property "Reference" "#PWR" (at 0 -3.81 0)
        (effects (font (size 1.27 1.27)) hide)
      )
			(property "Value" "+3V3" (at 0 3.81 0)
        (effects (font (size 1.27 1.27)))
      )
			(property "Footprint" "" (at 0 0 0)
        (effects (font (size 1.27 1.27)) hide)
      )
			(property "Datasheet" "" (at 0 0 0)
        (effects (font (size 1.27 1.27)) hide)
      )
			(symbol "+3V3_0_1"
        (polyline
          (pts (xy -1.27 1.27) (xy 0 2.54) (xy 1.27 1.27))
          (stroke (width 0) (type default))
          (fill (type none))
        )
        (polyline
          (pts (xy 0 0) (xy 0 2.54))
          (stroke (width 0) (type default))
          (fill (type none))
        )
      )
			(symbol "+3V3_1_1"
				(pin power_in line (at 0 0 90) (length 0) hide
          (name "+3V3" (effects (font (size 1.27 1.27))))
          (number "1" (effects (font (size 1.27 1.27))))
        )
      )
    )
  )"""

esp_at_x, esp_at_y = 50, 100
mpu_at_x, mpu_at_y = 170, 80


def esp_pin_abs(pin_num: int) -> tuple[float, float]:
    if pin_num <= 15:
        px = esp_at_x - 7.62
        py = esp_at_y + (20.32 - (pin_num - 1) * 2.54)
    else:
        px = esp_at_x + 7.62
        py = esp_at_y + (20.32 - (pin_num - 16) * 2.54)
    return (px, py)
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

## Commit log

2026-06-19 init: 项目初始化，添加 README 和 .gitignore
2026-06-19 refactor: 改用PM11电池模块(自带充电+升压5V), 移除TP4056, 简化载板设计
2026-06-19 chore: 移除下载的HTML文件
2026-06-19 docs: 载板PCB接线表, 网络表, 立创EDA绘制步骤
2026-06-19 feat: 添加Wokwi仿真项目 (ESP32+MPU6050+LED)
    - diagram.json: 电路连接定义
    - wokwi.toml: Wokwi配置
    - main.cpp: 角度检测+久坐计时固件
    - 更新README进度表和项目结构
2026-06-20 docs: 重构项目文档, 修正成本, 添加模块存档
    - README.md: 项目总览, 修正成本为实际价格(¥91.22)
    - hardware/HARDWARE.md: 硬件设计文档(选型/BOM/接线/供电/PCB/3D底座)
    - firmware/FIRMWARE.md: 固件设计文档(架构/算法/状态机/BLE/电源管理)
    - hardware/module_pages/: 三个核心模块商品页HTML存档
    - esp32-c3-mini.html (¥35.67)
    - mpu6050-gy521.html (¥25.55)
    - pm11-battery.html (¥19.00)
2026-06-20 feat(hardware): Phase 1 - ESP32-C3 + MPU6050 carrier board PCB
    Hardware Design (KiCad 7):
    - J1: ESP32-C3 Mini 2x9 pin header connector
    - J2: MPU6050 GY-521 1x8 pin header connector
    - Board: 80x50mm, 2-layer, 1.6mm FR-4
    - GND copper pour on bottom layer
    - I2C pull-up ready (for Phase 2)
    Files:
    - hardware/kicad/SedentaryDetector.kicad_sch
    - hardware/kicad/SedentaryDetector.kicad_pcb
    - hardware/kicad/SedentaryDetector.kicad_pro
    - hardware/TROUBLESHOOTING.md (踩坑记录)
    Verified:
    - kicad-happy analysis: 0 PCB errors
    - GND connected via copper pour
    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
    [SedentaryDetector.kicad_pcb, SedentaryDetector.kicad_sch]
2026-06-20 Add critical routing traces between connectors
    Routes added on F.Cu layer:
    - 3V3: J1.p10 -> J2.p1 (2 segments, 0.254mm)
    - I2C_SDA: J1.p7 -> J2.p4 (1 segment, 0.254mm)
    - I2C_SCL: J1.p8 -> J2.p3 (2 segments, 0.254mm)
    - INT: J1.p5 -> J2.p8 (2 segments, 0.254mm)
    - kicad-happy analysis: 0 errors, GND via copper pour
    - Power net 3V3 correctly routed with 0.254mm traces
    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
    [SedentaryDetector.kicad_pcb]
2026-06-20 docs(hardware): update troubleshooting with PCB format issues
    Added 3 new issues:
    - #4: Boolean values must be true/false (not yes/no) in KiCad 7
    - #5: Footprint uses tstamp not uuid
    - #6: Pad definitions require tstamp field
    Added best practices section for hand-writing KiCad files
    Recommended workflow: copy from demo → edit in GUI → save
2026-06-20 feat(hardware): regenerate PCB with KiCad 9 Python API
    Replace hand-written S-expression PCB with API-generated file:
    - Uses KiCad 9 AppImage Python API (pcbnew via AppRun)
    - Board: 50x35mm, 2-layer
    - J1: ESP32-C3 Mini 2x9 through-hole header
    - J2: MPU6050 1x8 through-hole header
    - GND zone on B.Cu layer
    - KiCad 9 CLI export OK
    - kicad-happy analysis: 0 errors, 0 warnings
    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
    [SedentaryDetector.kicad_pcb]
2026-06-20 docs(hardware): add KiCad 9 Python API troubleshooting
    - Issue #7: KiCad 9 API environment setup (AppRun required)
    - Document API changes: SetPadType→SetAttribute, PAD_ATTRIB_PTH
    - Add recommended KiCad 9 Python workflow
2026-06-20 fix(hardware): correct pin spacing to 2.54mm, add I2C/INT routing
    PCB fixes:
    - Row spacing: 24.5mm -> 2.54mm (standard 0.1in pitch)
    - Board: 50x35mm (per AGENTS.md)
    - J1: 2x15 @ (-15, -17.8)mm
    - J2: 1x8 @ (10, -7.6)mm
    - No overlap between connectors
    Routing added on F.Cu:
    - I2C_SDA: J1.p7 -> J2.p4
    - I2C_SCL: J1.p8 -> J2.p3
    - 3V3: J1.p2 -> J2.p1
    - MPU_INT: J1.p5 -> J2.p8
    GND: B.Cu copper pour
    [SedentaryDetector.kicad_pcb]
2026-06-20 chore: add .gitignore for KiCad backup/generated files
2026-06-20 fix(hardware): use absolute pad coordinates, fix connector overlap
    - Use absolute pad positions (not relative to footprint)
    - J1: x=[-13, -10.5], J2: x=[8] - separated by 18.5mm
    - 4 traces: I2C_SDA, I2C_SCL, 3V3, MPU_INT on F.Cu
    - GND copper pour on B.Cu
    - kicad-happy: 0 errors, PCB passes analysis
    [SedentaryDetector.kicad_pcb]
2026-06-20 fix(hardware): correct J1 row spacing to 23.5mm
    ESP32-WROOM-32 2x15 connector:
    - Row spacing: 23.5mm (between left/right columns)
    - Pin pitch: 2.54mm (vertical, within each column)
    - J1 at x=-18mm (left column), right column at x=-18+23.5=5.5mm
    J2 MPU6050 1x8 at x=12mm
    Routing: I2C_SDA, I2C_SCL, 3V3, MPU_INT
    [SedentaryDetector.kicad_pcb]
2026-06-20 fix(hardware): clear ratsnest (net assignments deferred to routing phase)
    - Removed all pad net assignments to avoid ratsnest lines
    - Nets still defined for later routing use
    - No blue connection lines on PCB view
    [SedentaryDetector.kicad_pcb]
2026-06-20 docs: add pcbnew API pitfalls and workflow to AGENTS.md
    - Absolute pad coordinates (KiCad 10 behavior)
    - Clear ratsnest before routing
    - Never hand-write S-expressions
    - Layout-first workflow (place -> verify -> route)
    - ESP32-WROOM-32 dimensions: 23.5mm row spacing
2026-06-20 feat(hardware): detailed silk annotations on PCB
    Added silk labels:
    - J1: connector name, pin functions (GND,3V3,INT,SDA,SCL,VIN)
    - J2: pin functions (VCC,GND,SCL,SDA,INT)
    - Row spacing dimension line: 23.5mm
    - Mounting holes: MH1-4 with M3 spec
    - Board info: Project name, size, GND pour note
    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
    [SedentaryDetector.kicad_pcb]
2026-06-20 fix(schematic): generate valid KiCad 10 schematic
    Replace broken gen_sch.py output with proper KiCad 10 format:
    - J1: 2x15 ESP32-WROOM-32 connector (30 pins, inline symbol)
    - J2: 1x8 MPU6050-GY521 connector (8 pins, inline symbol)
    - Uses tab indentation (KiCad 10 requirement)
    - Pin UUIDs generated properly
    - Exports to PDF successfully
    [SedentaryDetector.kicad_sch]
2026-06-20 fix(hardware): silk labels within board bounds, correct PDF export
    - Fix J2 pin label Y coordinates (was using X position by mistake)
    - Adjust all silk positions to stay within 80x50mm board
    - KiCad 10 PDF export: use --mode-single --scale 0 --ibt
    [SedentaryDetector.kicad_pcb]
2026-06-20 fix(hardware): correct J2 silk positions, update HARDWARE.md with ESP32 pinout
    - J2 MPU6050 labels moved outside module outline
    - HARDWARE.md updated with ESP32-WROOM-32 pinout image
    - Added ESP32 pinout reference image to hardware/images/
    [SedentaryDetector.kicad_pcb]
2026-06-20 fix(hardware): final PCB layout with clean pin labels
    - Removed J1/J2 reference text, only keep pin labels
    - Added MCU direction arrow (USB side down)
    - J1 (2x15): Left: EN,GPIO15-2; Right: GND,VIN,GPIO23-13,GND
    - J2 (1x8): VCC,GND,SCL,SDA,XDA,XCL,AD0,INT
    - Updated HARDWARE.md with correct pin assignments
    [SedentaryDetector.kicad_pcb]
2026-06-20 fix(hardware): final clean PCB - only pin labels
    - J1: Left: EN,GPIO15-2; Right: GND,VIN,GPIO23-13,GND
    - J2: VCC,GND,SCL,SDA,XDA,XCL,AD0,INT
    - No J1/J2 titles, no dimension lines, no module outlines
    - B.Cu GND copper pour
    [SedentaryDetector.kicad_pcb]
2026-06-20 fix(hardware): correct ESP32-WROOM-32 pinout and remove traces
    - Left P1-P15: 3V3,EN,GPIO36-12,GND,VIN (correct order)
    - Right P16-P30: GPIO23-15,GND,3V3,NC
    - J2 P1-P8: VCC,GND,SCL,SDA,XDA,XCL,AD0,INT
    - Removed all routing traces (user will route in KiCad GUI)
    - Added HARDWARE_PINOUT.md documentation
    [SedentaryDetector.kicad_pcb]
2026-06-20 fix(hardware): correct ESP32 pinout to 15+14 pins per user spec
    PCB silk:
    - Left: P1-P15 (3V3,EN,GPIO36-12,GND,VIN)
    - Right: P16-P29 (GPIO23,22,21,GND,19,18,5,17,16,4,2,15,GND,3V3) - 14 pins
    - J2: P1-P8 (VCC,GND,SCL,SDA,XDA,XCL,AD0,INT)
    - No NC, no traces, no zones
    Docs:
    - Rewrote HARDWARE.md with correct pinout
    - Right column has 14 pins (not 15)
    - MPU6050 dimensions: 15.6x20.2mm
    - Updated wiring table and BOM
    [SedentaryDetector.kicad_pcb]
2026-06-20 PCB silk: L-P1~L-P15, R-P1~R-P14, J2-P1~J2-P8 format
    [SedentaryDetector.kicad_pcb]
2026-06-20 PCB silk: R-P1~R-P15 (both columns 15 labels)
    [SedentaryDetector.kicad_pcb]
2026-06-20 feat(hardware): enlarge board to 100x80mm, correct pin placement
    [SedentaryDetector.kicad_pcb]
2026-06-20 docs: restore PM11 power module
2026-06-20 fix(hardware): remove auto Edge.Cuts, add GND pour, fix silk size
    [SedentaryDetector.kicad_pcb]
2026-06-20 feat(hardware): auto-route 4 signals with spaced channels
    [SedentaryDetector.kicad_pcb]
2026-06-20 Revert: remove all traces, user to route manually
    [SedentaryDetector.kicad_pcb]
2026-06-20 Phase 2: routing strategy + net assignments
    [SedentaryDetector.kicad_pcb]
2026-06-20 Revert: remove Edge.Cuts, user to draw
    [SedentaryDetector.kicad_pcb]
2026-06-20 docs(sch): add J3 POWER_2P power connector
    [SedentaryDetector.kicad_sch]
2026-06-20 feat(hardware): add board outline through MH
    [SedentaryDetector.kicad_pcb, SedentaryDetector.kicad_sch]
2026-06-20 fix(hardware): border 3mm outside MH, 53x68mm
    [SedentaryDetector.kicad_pcb]
2026-06-20 V0.4: Gerber export ready, J3 power, M4 holes
    [SedentaryDetector-B_Cu.gbl, SedentaryDetector-B_Mask.gbs, SedentaryDetector-B_Silkscreen.gbo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]
2026-06-20 chore(hardware): clean up directory structure
    [SedentaryDetector-B_Cu.gbl, SedentaryDetector-B_Mask.gbs, SedentaryDetector-B_Silkscreen.gbo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]
2026-06-22 docs: 子模块路径重编号 04 → 02
    与 monorepo 目录 Projects/02-APP-Sedentary-Detector-ESP32C3 对齐。
2026-06-22 docs: 同步仓库重命名为 APP-Sedentary-Detector-ESP32
    更新文档路径与说明，移除 ESP32C3 遗留命名备注。
2026-06-23 refactor: software/hardware 目录重组并整理文档
    迁入 firmware/simulation 至 software/、scripts 至 hardware/；新增 ARCHITECTURE.md 区分已实现与规划；瘦身 README 与 AGENTS.md。
2026-06-23 chore: 移除 software 目录，固件改由 03/04 项目维护
    久坐检测器本仓库仅保留 hardware；GY-87 与 OLED 联调见 sibling 项目。
2026-06-23 docs: 仅保留根目录 README，删除 hardware/README.md
    KiCad 打开方式并入根 README。
2026-06-23 docs: 载板未布线，等 03/04 软件联调稳定后再走线打样
    同步 J2 已对齐 GY-87 的说明；调整 PCB/J4 布局坐标。
    [SedentaryDetector.kicad_pcb]
